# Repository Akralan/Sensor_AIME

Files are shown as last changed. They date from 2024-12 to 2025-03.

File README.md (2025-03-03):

# Solution IoT pour un capteur de gaz connecté

## 1. Introduction
**Contexte et Motivation :**  
Ce projet propose une solution IoT complète autour d’un capteur de gaz, intégrant la conception électronique (PCB, amplification, filtrage), le développement logiciel (firmware embarqué sur ESP32, interface Node-RED) et une application mobile (AppInventor).

**Description Générale :**  
Le système permet de mesurer la concentration de gaz via un capteur dédié, de conditionner le signal et de transmettre les données via LoRa ou Bluetooth. L’utilisateur peut ensuite visualiser les mesures en temps réel et interagir avec le dispositif depuis une interface Node-RED ou une application mobile.

---

## 2. Table des Matières
- [1. Introduction](#1-introduction)
- [2. Table des Matières](#2-table-des-matières)
- [3. Aperçu du Projet](#3-apercu-du-projet)
- [4. Matériel (Hardware)](#4-matériel-hardware)
- [5. Logiciel (Software)](#5-logiciel-software)
- [6. Installation et Mise en Service](#6-installation-et-mise-en-service)
- [7. Utilisation](#7-utilisation)
- [8. Contacts et Auteurs](#8-contacts-et-auteurs)

---

## 3. Aperçu du Projet

**Résumé Fonctionnel :**  
1. Mesure de gaz via un capteur spécifique et circuits d’acquisition (amplification, filtrage).  
2. Traitement et envoi des données par un microcontrôleur (ESP32).  
3. Visualisation en temps réel sur Node-RED et application mobile (AppInventor).

**Architecture Globale :**  
- **Capteur de Gaz** : Convertit la concentration de gaz en signal électrique.
- **Chaîne d’Acquisition** : Simulations LTSpice et conception PCB (fichiers dans `Chaine acquisition` et `PCB`).  
- **Microcontrôleur (ESP32)** : Gère la communication (LoRa/BLE) et le traitement des mesures avant l'enregistrement dans la base de données (code dans `Code/AIME`).  
- **Interface Node-RED** : Flows pour l’affichage des donneés dans une interface web simpliste (dossier `NodeRed`).  
- **Application Mobile** : Réalisée sous AppInventor (dossier `AppInventor` à la racine).

---

## 4. Matériel (Hardware)

**Liste des Composants :**
- **Capteur de gaz** (spécifique au projet ou type MQ)  
- **ESP32** (ou carte équivalente)  
- **Modules de communication** (LoRa, Bluetooth, etc.)  
- **Composants d’amplification et filtrage** (ex. LTC1050, résistances, condensateurs)  
- **PCB** (dossier `PCB`)  
  - Fichiers KiCad (ex. `GazSensor.kicad_pro`)  
  - Dossier `pcb_aime` pour les fichiers de fabrication

**Design et Schémas :**  
- Fichiers KiCad dans le dossier `PCB`.  
- Simulations LTSpice dans `Chaine acquisition`.

**Procédure d’Assemblage :**  
- Ouvrir le projet KiCad pour consulter le routage et générer les fichiers Gerber.  
- Souder les composants en suivant le BOM (Bill Of Materials) et le placement défini par le PCB.

---

## 5. Logiciel (Software)

**Composants Logiciels :**
- **Firmware Embarqué** : Dossier `Code/AIME` (PlatformIO)  
- **Interface Node-RED** : Fichier `flows.json` dans le dossier `NodeRed`  
- **Application Mobile** : Dossier `AppInventor` (fichiers sources AppInventor)

**Organisation du Code :**
- `Code/AIME/`
  - **platformio.ini** : Fichier de configuration PlatformIO  
  - **src/** : Code source principal (ex. `main.cpp`, `gaz_sensor.cpp`)  
  - **include/** : Fichiers d’en-tête (ex. `gaz_sensor.h`)  
  - **lib/** : Bibliothèques locales (si nécessaires)  
  - **test/** : Éventuels tests unitaires  
  - **.vscode/** : Paramètres spécifiques VS Code pour PlatformIO

---

## 6. Installation et Mise en Service

### Prérequis
- **Visual Studio Code (VS Code)**
- **PlatformIO IDE** : Extension à installer dans VS Code
- **C/C++ Extension** (recommandée)
- **Bibliothèques** : Spécifiées dans la section `[lib_deps]` du fichier `platformio.ini`

### Guide Pas-à-Pas
1. **Cloner le Dépôt**  
    (Depuis un terminal)
    
    ```
    git clone https://github.com/<user>/Sensor_AIME.git
    ```

2. **Ouvrir le Projet avec VS Code**  
    - Lancer VS Code  
    - Sélectionner *Open Folder* et choisir `Sensor_AIME/Code/AIME`

3. **Installer PlatformIO**  
    - Dans VS Code, aller dans l’onglet *Extensions*  
    - Rechercher “PlatformIO IDE” et cliquer sur *Install*

4. **Compiler le Firmware**  
    - Ouvrir la palette de commandes (Ctrl+Shift+P)  
    - Taper `PlatformIO: Build`  
    - Vérifier que la compilation se déroule sans erreur

5. **Téléverser le Firmware**  
    - Connecter la carte ESP32 au PC via USB  
    - Dans la palette de commandes, sélectionner `PlatformIO: Upload`  
    - Vérifier que le port série est correctement configuré dans `platformio.ini`

6. **Configurer Node-RED**  
    - Installer Node-RED si besoin (ex. `npm install -g node-red`)  
    - Lancer Node-RED via la commande `node-red`  
    - Importer le flow depuis `NodeRed/flows.json`

7. **Installer l’Application Mobile (AppInventor)**  
    - Le dossier `AppInventor` se trouve à la racine du dépôt  
    - Ouvrir le projet AppInventor sur [ai2.appinventor.mit.edu](https://ai2.appinventor.mit.edu/)  
    - Compiler le projet et installer l’APK sur un smartphone Android

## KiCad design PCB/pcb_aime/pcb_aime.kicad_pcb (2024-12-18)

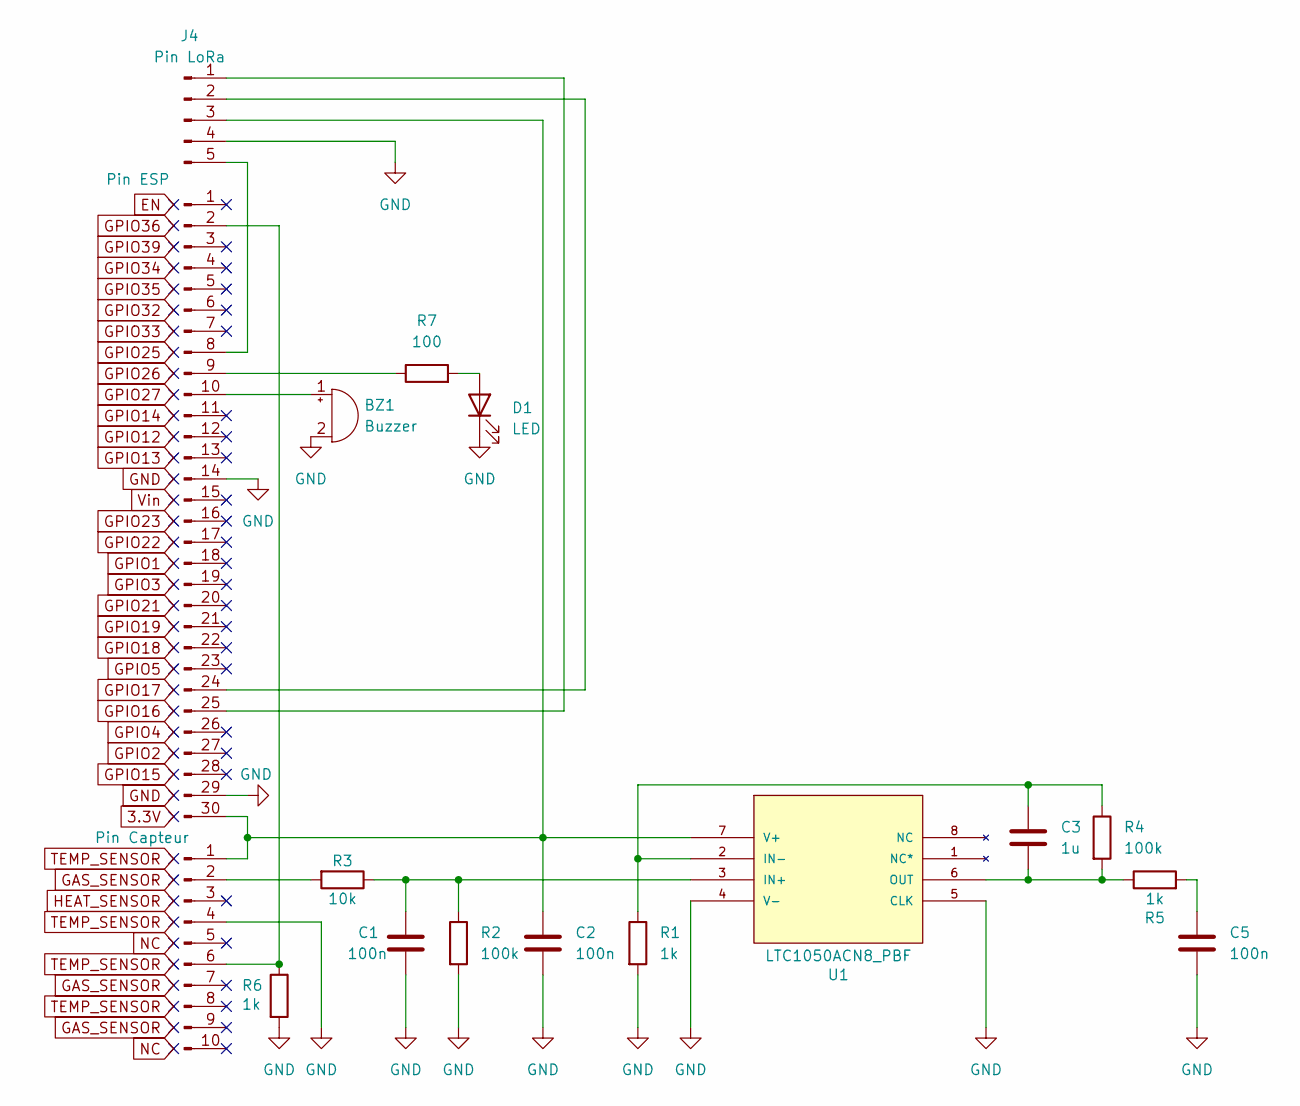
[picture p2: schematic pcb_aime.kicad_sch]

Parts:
BZ1: Buzzer; Buzzer_12x9.5RM7.6
C1, C2, C5: 100n; C_0805_2012Metric
C3: 1u; C_0805_2012Metric
D1: LED; LED_0805_2012Metric
J1: Pin ESP; XCVR_ESP32-C3-DEVKITM-1
J2: Pin Capteur; GazSensor
J4: Pin LoRa; PinHeader_1x05_P2.54mm_Vertical
R1, R5, R6: 1k; R_0805_2012Metric
R2, R4: 100k; R_0805_2012Metric
R3: 10k; R_0805_2012Metric
R7: 100; R_0805_2012Metric
U1: LTC1050ACN8_PBF; PDIP-8_N; MANUFACTURER_PART_NUMBER ltc1050acn8

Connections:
GND: BZ1.2 (-), C1.1, C2.1, C5.1, D1.1 (K), J1.14, J1.29, J2.4, J4.4, R1.2, R2.2, R6.2, U1.4 (V-), U1.5 (CLK)
unnamed: BZ1.1 (+), J1.10
unnamed: C5.2, R5.2
unnamed: D1.2 (A), R7.2
unnamed: J1.2, J2.6, R6.1
unnamed: J1.8, J4.5
unnamed: J1.9, R7.1
unnamed: J1.24, J4.2
unnamed: J1.25, J4.1
unnamed: C2.2, J1.30, J2.1, J4.3, U1.7 (V+)
unnamed: J2.2, R3.2
unnamed: C1.2, R2.1, R3.1, U1.3 (IN+)
unnamed: C3.2, R1.1, R4.1, U1.2 (IN-)
unnamed: C3.1, R4.2, R5.1, U1.6 (OUT)

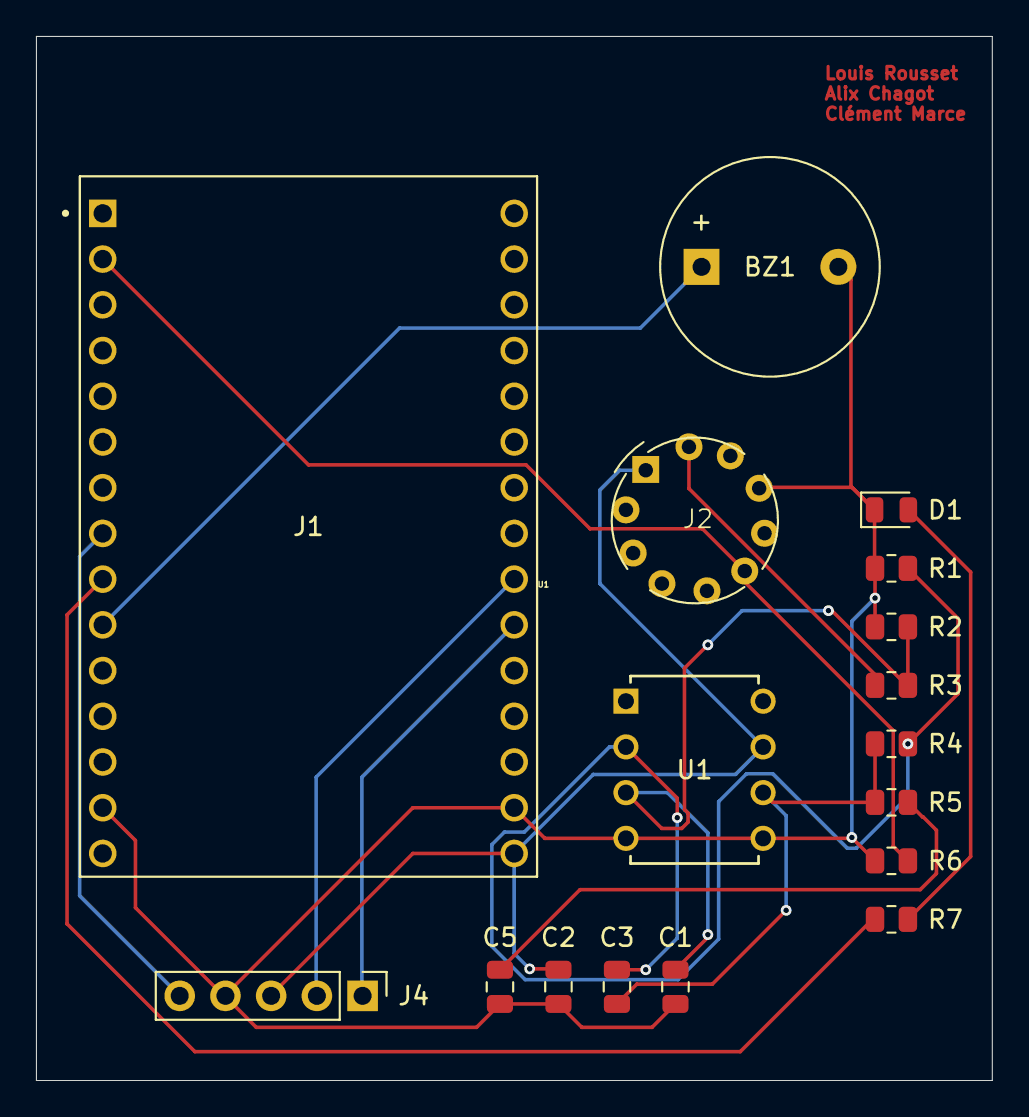
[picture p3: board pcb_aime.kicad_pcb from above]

Board: 2 copper layers, 53.1 x 58.0 mm, 17 parts (0 on the bottom side), 14 nets.

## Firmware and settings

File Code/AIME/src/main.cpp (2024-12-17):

#include <Arduino.h>
#include "gaz_sensor.h"
#include "oled_screen.h"
#include "BluetoothSerial.h"

#include <HardwareSerial.h>

// Définition du port série pour LoRa (UART2)
#define RXD2 16 // GPIO16 (RX)
#define TXD2 17 // GPIO17 (TX)
HardwareSerial LoRaSerial(2); // Utilise UART2

void setup() {
  Serial.begin(9600); // Moniteur série
  LoRaSerial.begin(9600, SERIAL_8N1, RXD2, TXD2); // Port série LoRa, 9600 baud

  // Envoyer une commande AT pour vérifier la connexion
  LoRaSerial.println("AT");
  delay(5000);

  // Lire la réponse
  while (LoRaSerial.available()) {
    String response = LoRaSerial.readString();
    Serial.print("Réponse LoRa: ");
    Serial.println(response);
  }

  // Récupérer l'EUI64
  Serial.println("Demande de l'EUI64...");
  LoRaSerial.println("sys get hweui"); // Commande pour l'EUI (à vérifier dans la documentation)
  delay(1000);
}

void loop() {
    if (LoRaSerial.available()) {
        String response = LoRaSerial.readString();
        Serial.print("EUI64: ");
        Serial.println(response);
    }
}


/*#define LED 4

#define BOARD_TYPE "ESP32"
#define SENSOR_TYPE "MQ-9"
#define ANALOG_PIN 36
#define VOLTAGE_RESOLUTION 5.0
#define ADC_BIT_RESOLUTION 10
#define RATIO_CLEAN_AIR 9.83 // Ratio du capteur en air propre (selon datasheet)

BluetoothSerial SerialBT;
GazSensor mq9(BOARD_TYPE, SENSOR_TYPE, ANALOG_PIN, VOLTAGE_RESOLUTION, ADC_BIT_RESOLUTION, RATIO_CLEAN_AIR);
bool blink = false;
bool ledState = false;
unsigned long previousMillis = 0;

void setup() {
    Serial.begin(9600);
    SerialBT.begin("ESP32_BT_Alix");

    pinMode(LED, OUTPUT);
    digitalWrite(LED, ledState);

    mq9.begin(); // Initialisation et calibration du capteur

    OLEDManager oled;
    if (!oled.begin()) {
        Serial.println("Erreur d'initialisation de l'écran !");
        while (true); // Arrête le programme si l'initialisation échoue
    }

    oled.reset(); // Réinitialisation de l'écran

    // Affichage de texte sur différentes lignes
    oled.displayText(0, "Bonjour !");
    oled.displayText(1, "Ligne 1 : Test");
    oled.displayText(2, "Ligne 2 : OK");
}

void loop() {
    unsigned long currentMillis = millis(); // Temps actuel

    if (Serial.available()) {
        SerialBT.write(Serial.read()); // Envoie les données reçues via Bluetooth
    }
    if (SerialBT.available()) {
        int data = SerialBT.read();
        switch(data) {
            case 1:
                blink = false;
                digitalWrite(LED, HIGH);
                break;
            case 2:
                blink = false;
                digitalWrite(LED, LOW);
                break;
            case 3:
                blink = true;
                break;
            default:
                break;
        }
        Serial.println(data); // Affiche les données Bluetooth sur le port série
    }
    if (currentMillis - previousMillis >= 1000) {
        previousMillis = currentMillis; // Met à jour le moment du dernier changement

        // Inverse l'état de la LED
        if (blink) {
            ledState = !ledState;
            digitalWrite(LED, ledState);
        }
        float ch4_ppm = mq9.readPPM("CH4");
        Serial.println(ch4_ppm);
        SerialBT.write(ch4_ppm); // Envoie les données reçues via Bluetooth
    }
}*/

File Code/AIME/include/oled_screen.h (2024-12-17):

#include <Adafruit_GFX.h>
#include <Adafruit_SSD1306.h>

// Configuration de l'écran OLED
#define SCREEN_WIDTH 128 // Largeur de l'écran OLED
#define SCREEN_HEIGHT 64 // Hauteur de l'écran OLED
#define OLED_RESET -1    // Pin de reset (-1 si pas utilisé)
#define SSD1306_I2C_ADDRESS 0x3C

// Classe pour gérer un écran SSD1306
class OLEDManager {
private:
    Adafruit_SSD1306* display;

public:
    // Constructeur
    OLEDManager() {
        display = new Adafruit_SSD1306(SCREEN_WIDTH, SCREEN_HEIGHT, &Wire, OLED_RESET);
    }

    // Initialisation de l'écran
    bool begin() {
        if (!display->begin(SSD1306_I2C_ADDRESS, OLED_RESET)) {
            Serial.println("Échec de l'initialisation de l'écran OLED !");
            return false;
        }
        display->clearDisplay();
        display->display();
        Serial.println("Écran OLED initialisé !");
        return true;
    }

    // Réinitialisation de l'écran
    void reset() {
        display->clearDisplay();
        display->display();
        Serial.println("Écran OLED réinitialisé !");
    }

    // Afficher un texte sur une ligne spécifique
    void displayText(int line, const String& text) {
        if (line < 0 || line > 7) { // Vérification que la ligne est valide (max 8 lignes pour 64px avec une police standard de 8px)
            Serial.println("Ligne invalide !");
            return;
        }

        display->setTextSize(1);             // Taille du texte
        display->setCursor(0, line * 8);     // Définir la position en pixels (ligne * 8 pour espacement vertical)
        display->print(text);                // Afficher le texte
        display->display();                  // Mettre à jour l'écran
    }

    // Destructeur
    ~OLEDManager() {
        delete display;
    }
};

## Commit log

2024-12-17 Ajout du code de l'esp32 pour se connecter à une application en bluetooth ainsi qu'à une base de donnée via un module LoRa afin de stocker les valeurs du capteur de gaz. Ajout du schéma électrique de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
2024-12-18 Modifications du code, ajout de la schématique et de la PCB définit pour avoir : Buzzer, led, capteur gaz et sa chaine d'acquisition, pin pour le module LoRa
    [pcb_aime.kicad_pcb, pcb_aime.kicad_sch]
2024-12-18 Ajout du nodered qui affiche sur le dashboard un chart des valeurs de gaz, la dernière valeur connus et une notification en cas de dépassement d'une valeur limite
    [pcb_aime.kicad_pcb]
2025-01-21 finishing some things
    [pcb_aime.kicad_sch]
2025-02-25 ajout du code de l'application

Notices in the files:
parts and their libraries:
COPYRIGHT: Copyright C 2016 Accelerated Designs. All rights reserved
